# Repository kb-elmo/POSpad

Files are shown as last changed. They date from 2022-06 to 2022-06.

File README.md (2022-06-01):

# POSpad

[][cc-by-nc-sa]<a href="https://ko-fi.com/kb_elmo">kofibadge</a>

### 4-key / POS macropad

header

---

[STEP files for the case](case/)

[KiCAD PCB files](pcb/)

[Gerbers for PCB production](pcb/gerbers/)

[JLCPCB BOM](pcb/fab/pos_bom_jlc.csv)

[JLCPCB CPL](pcb/fab/pos_cpl_jlc.csv)

[Vial-QMK firmware](firmware/)

---

This work is licensed under a
[Creative Commons Attribution-NonCommercial-ShareAlike 4.0 International License][cc-by-nc-sa].

[][cc-by-nc-sa]

[cc-by-nc-sa]: http://creativecommons.org/licenses/by-nc-sa/4.0/
[cc-by-nc-sa-image]: https://licensebuttons.net/l/by-nc-sa/4.0/88x31.png
[cc-by-nc-sa-shield]: https://img.shields.io/badge/License-CC%20BY--NC--SA%204.0-lightgrey.svg

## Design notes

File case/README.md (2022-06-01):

# POSpad case

### These files are meant for 3D printing only! 

They are not suitable for CNC machining and trying to use them for that will most likely result in failure of the parts.

The top piece should be printed upside down with supports for the integrated plate to get the best looking results.  
The bottom can be printed without any supports in it's natural orientation.

The bottom part is a simple friction fit into the top.  
Make sure that everything works and is installed properly on the PCB when putting the case together.  
Removing the bottom piece later is not really easy.

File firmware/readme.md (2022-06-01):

# POSpad PCB

pos

Four key macropad that can be used for 2x2u POS keycaps

* Keyboard Maintainer: [kb-elmo](https://github.com/kb-elmo)
* Hardware Supported: POSpad PCB rev.1
* Hardware Availability: [Open source project](https://github.com/kb-elmo/POSpad)

Make example for this keyboard (after setting up your build environment):

    make kb_elmo/pos:default

Flashing example for this keyboard:

    make kb_elmo/pos:default:flash

See the [build environment setup](https://docs.qmk.fm/#/getting_started_build_tools) and the [make instructions](https://docs.qmk.fm/#/getting_started_make_guide) for more information. Brand new to QMK? Start with our [Complete Newbs Guide](https://docs.qmk.fm/#/newbs).

## Bootloader

Enter the bootloader in 3 ways:

* **Bootmagic reset**: Hold down the top left key and plug in the keyboard
* **Physical reset**: Briefly short the two contacts labeled "RESET" on the bottom of the PCB
* **Keycode in layout**: Press the key mapped to `RESET` if it is available

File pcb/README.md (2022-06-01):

# POSpad PCB

### Features

- In-switch backlight LEDs
- Powered by an Atmega32u2
- Basic ESD and overvoltage protection
- Centered USB type-C port for a detachable cable
- Fully programmable using [QMK](https://qmk.fm) and [Vial](https://get.vial.today)

---

### Preview

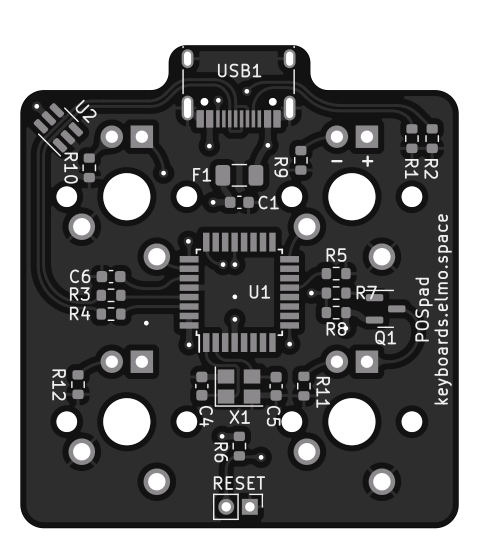
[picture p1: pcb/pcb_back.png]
pcb_back
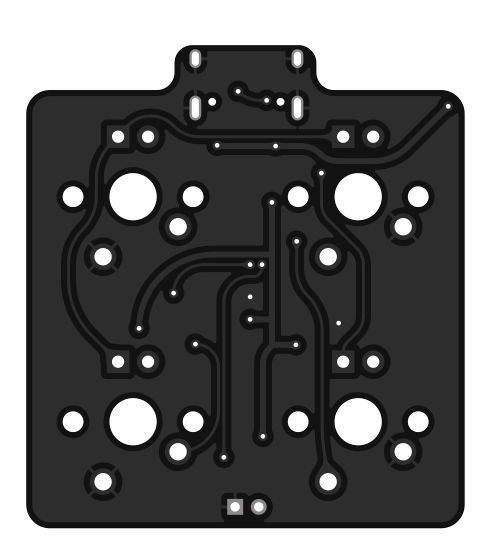
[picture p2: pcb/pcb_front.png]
pcb_front


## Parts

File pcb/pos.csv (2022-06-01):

Comment | Designator | Footprint | LCSC
10uF | C1 | Capacitor_SMD:C_0603_1608Metric | C19702
22pF | C4,C5 | Capacitor_SMD:C_0603_1608Metric | C1653
1uF | C6 | Capacitor_SMD:C_0603_1608Metric | C15849
Polyfuse_Small | F1 | Fuse:Fuse_1206_3216Metric | C69688
MX-LED | MX1,MX2,MX3,MX4 | MX_Only:MXOnly-1U
AO3401A | Q1 | Package_TO_SOT_SMD:SOT-23 | C15127
5.1k | R1,R2 | Resistor_SMD:R_0603_1608Metric | C23186
22 | R3,R4 | Resistor_SMD:R_0603_1608Metric | C23345
10k | R5,R6,R8 | Resistor_SMD:R_0603_1608Metric | C25804
100r | R7 | Resistor_SMD:R_0603_1608Metric | C22775
1k | R9,R10,R11,R12 | Resistor_SMD:R_0603_1608Metric | C21190
SW_Push | RESET1 | Connector_PinHeader_2.00mm:PinHeader_1x02_P2.00mm_Vertical | C318884
ATmega32U2-AU | U1 | Package_QFP:TQFP-32_7x7mm_P0.8mm | C618733
SRV05-4 | U2 | Package_TO_SOT_SMD:SOT-23-6 | C85364
USB_C_Receptacle_USB2.0 | USB1 | Connector_USB:USB_C_Receptacle_HRO_TYPE-C-31-M-12 | C165948
Crystal_GND24_Small | X1 | Crystal:Crystal_SMD_3225-4Pin_3.2x2.5mm | C13738

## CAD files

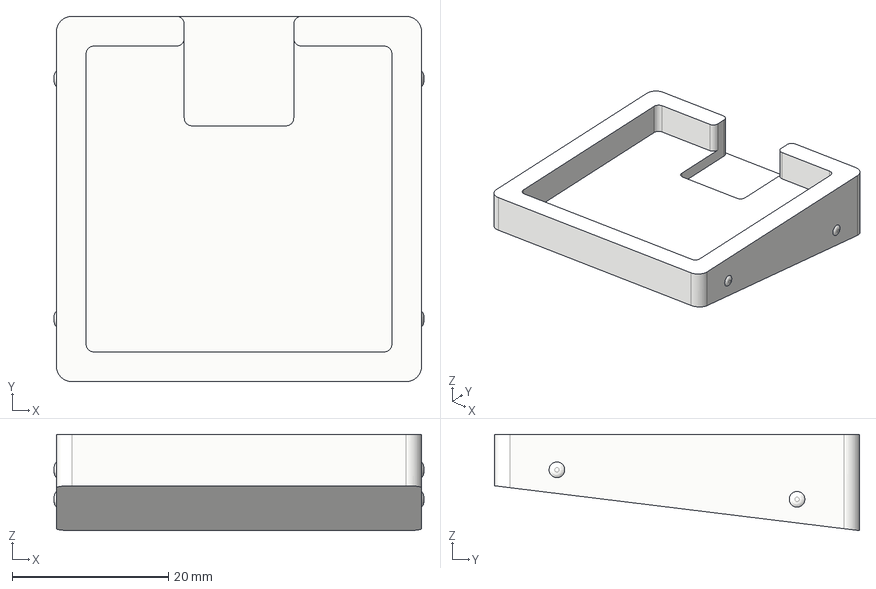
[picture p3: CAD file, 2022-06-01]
case/pos_bottom.step
47.3 x 46.7 x 12.3 mm

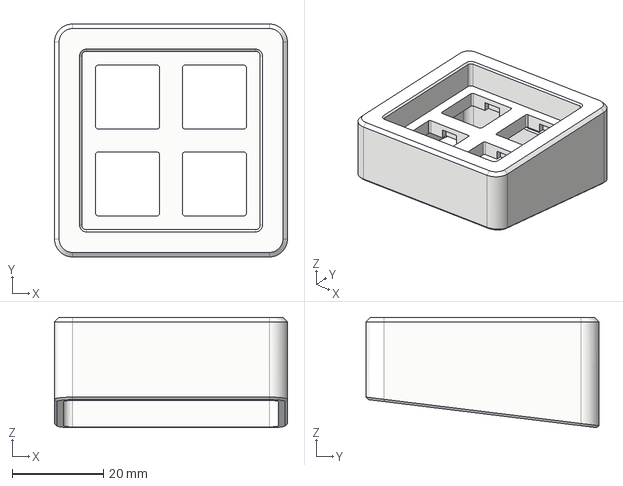
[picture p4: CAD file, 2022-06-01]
case/pos_top.step
51.1 x 51.1 x 24.2 mm

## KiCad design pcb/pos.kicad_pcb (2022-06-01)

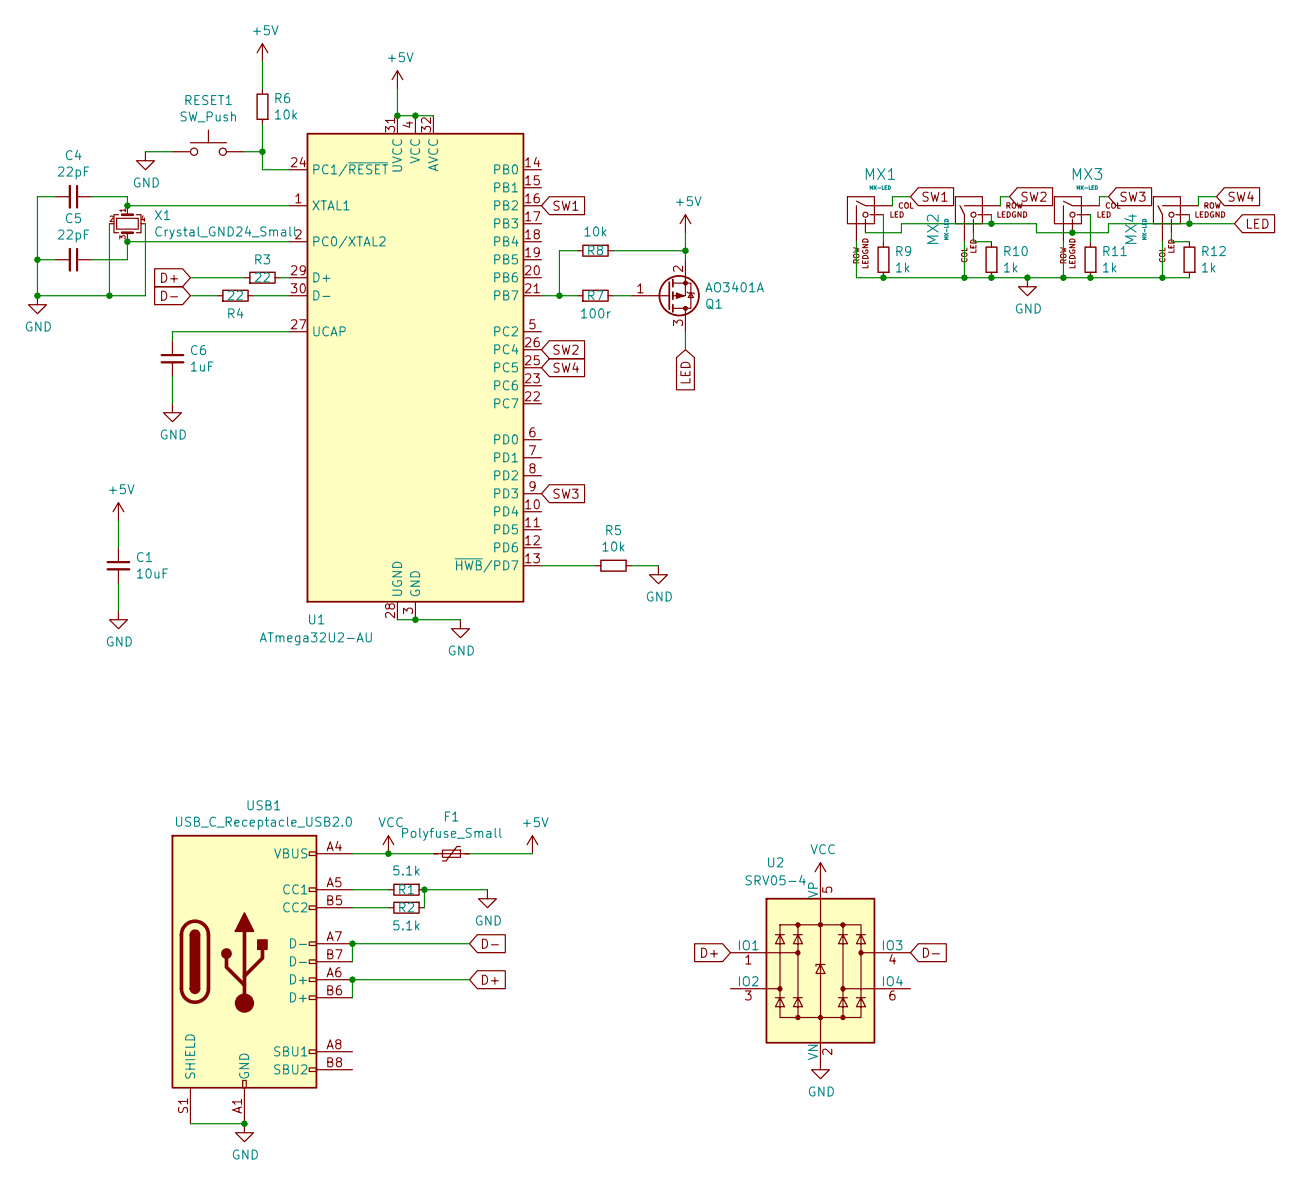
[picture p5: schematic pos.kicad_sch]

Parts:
C1: 10uF; C_0603_1608Metric; LCSC C19702
C4, C5: 22pF; C_0603_1608Metric; LCSC C1653
C6: 1uF; C_0603_1608Metric; LCSC C15849
F1: Polyfuse_Small; Fuse_1206_3216Metric; LCSC C69688
MX1, MX2, MX3, MX4: MX-LED; MXOnly-1U
Q1: AO3401A; SOT-23; LCSC C15127
R1, R2: 5.1k; R_0603_1608Metric; LCSC C23186
R3, R4: 22; R_0603_1608Metric; LCSC C23345
R5, R6, R8: 10k; R_0603_1608Metric; LCSC C25804
R7: 100r; R_0603_1608Metric; LCSC C22775
R9, R10, R11, R12: 1k; R_0603_1608Metric; LCSC C21190
RESET1: SW_Push; PinHeader_1x02_P2.00mm_Vertical; LCSC C318884
U1: ATmega32U2-AU; TQFP-32_7x7mm_P0.8mm; LCSC C618733
U2: SRV05-4; SOT-23-6; LCSC C85364
USB1: USB_C_Receptacle_USB2.0; USB_C_Receptacle_HRO_TYPE-C-31-M-12; LCSC C165948
X1: Crystal_GND24_Small; Crystal_SMD_3225-4Pin_3.2x2.5mm; LCSC C13738

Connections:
+5V: C1.1, F1.1, Q1.2 (S), R6.2, R8.1, U1.4 (VCC), U1.31 (UVCC), U1.32 (AVCC)
D+: R3.1, U2.1 (IO1), USB1.A6 (D+), USB1.B6 (D+)
D-: R4.1, U2.4 (IO3), USB1.A7 (D-), USB1.B7 (D-)
GND: C1.2, C4.2, C5.2, C6.2, MX1.2 (ROW), MX2.1 (COL), MX3.2 (ROW), MX4.1 (COL), R1.1, R2.1, R5.1, R9.1, R10.1, R11.1, R12.1, RESET1.1, U1.3 (GND), U1.28 (UGND), U2.2 (VN), USB1.A1 (GND), USB1.A12 (GND), USB1.B1 (GND), USB1.B12 (GND), USB1.S1 (SHIELD), X1.2, X1.4; also elsewhere on the board
LED: MX1.4 (LEDGND), MX2.4 (LEDGND), MX3.4 (LEDGND), MX4.4 (LEDGND), Q1.3 (D)
unnamed: C4.1, U1.1 (XTAL1), X1.1
unnamed: C5.1, U1.2 (PC0/XTAL2), X1.3
unnamed: C6.1, U1.27 (UCAP)
unnamed: MX1.3 (LED), R9.2
unnamed: MX2.3 (LED), R10.2
unnamed: MX3.3 (LED), R11.2
unnamed: MX4.3 (LED), R12.2
unnamed: Q1.1 (G), R7.2
unnamed: R1.2, USB1.A5 (CC1)
unnamed: R2.2, USB1.B5 (CC2)
unnamed: R3.2, U1.29 (D+)
unnamed: R4.2, U1.30 (D-)
unnamed: R5.2, U1.13 (~HWB/PD7)
unnamed 18: R6.1, RESET1.2, U1.24 (PC1/~RESET); also elsewhere on the board
unnamed: R7.1, R8.2, U1.21 (PB7)
SW1: MX1.1 (COL), U1.16 (PB2)
SW2: MX2.2 (ROW), U1.26 (PC4)
SW3: MX3.1 (COL), U1.9 (PD3)
SW4: MX4.2 (ROW), U1.25 (PC5)
VCC: F1.2, U2.5 (VP), USB1.A4 (VBUS), USB1.A9 (VBUS), USB1.B4 (VBUS), USB1.B9 (VBUS)

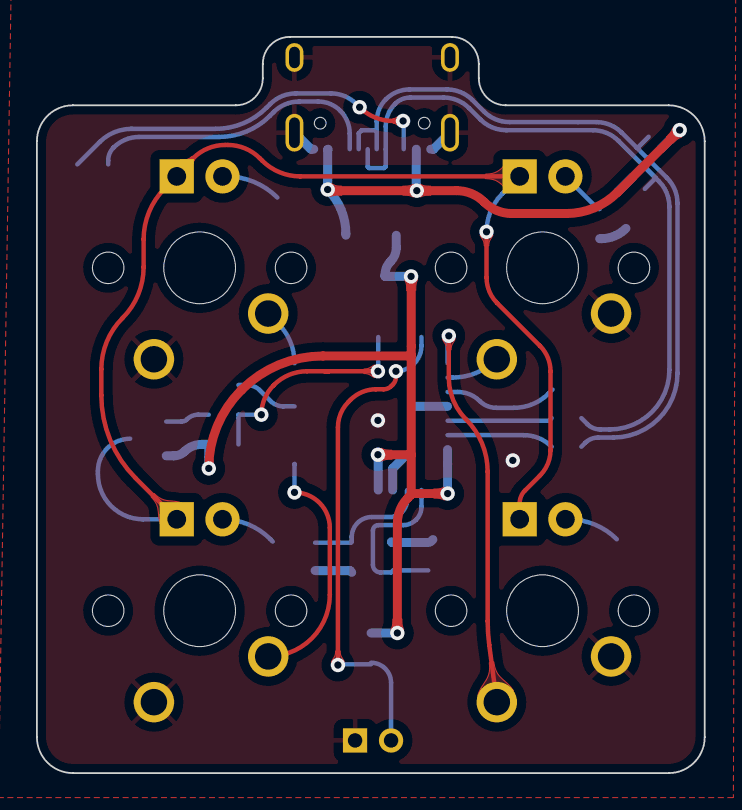
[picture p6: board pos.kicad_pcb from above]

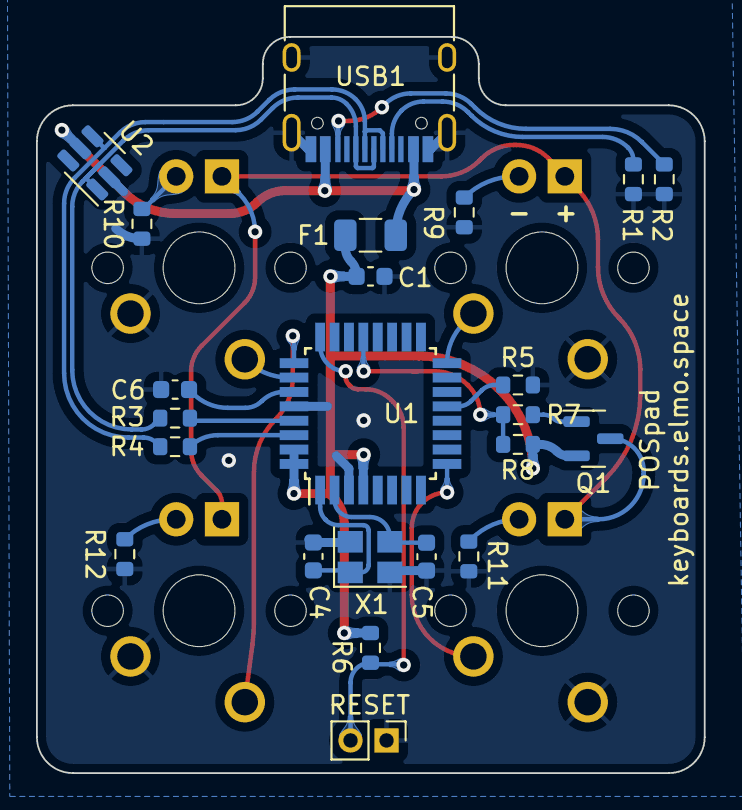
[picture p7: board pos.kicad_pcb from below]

Board: 2 copper layers, 37.1 x 40.9 mm, 27 parts (23 on the bottom side), 25 nets.

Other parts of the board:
RESET: SW_Push; PinHeader_1x02_P2.00mm_Vertical

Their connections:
GND: RESET.1; also elsewhere on the board
unnamed 18: RESET.2; also elsewhere on the board

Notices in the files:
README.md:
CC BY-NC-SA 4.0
